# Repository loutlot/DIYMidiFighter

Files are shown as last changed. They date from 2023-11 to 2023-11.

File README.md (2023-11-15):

# DIY Midi Fighter Thing tutorial.  

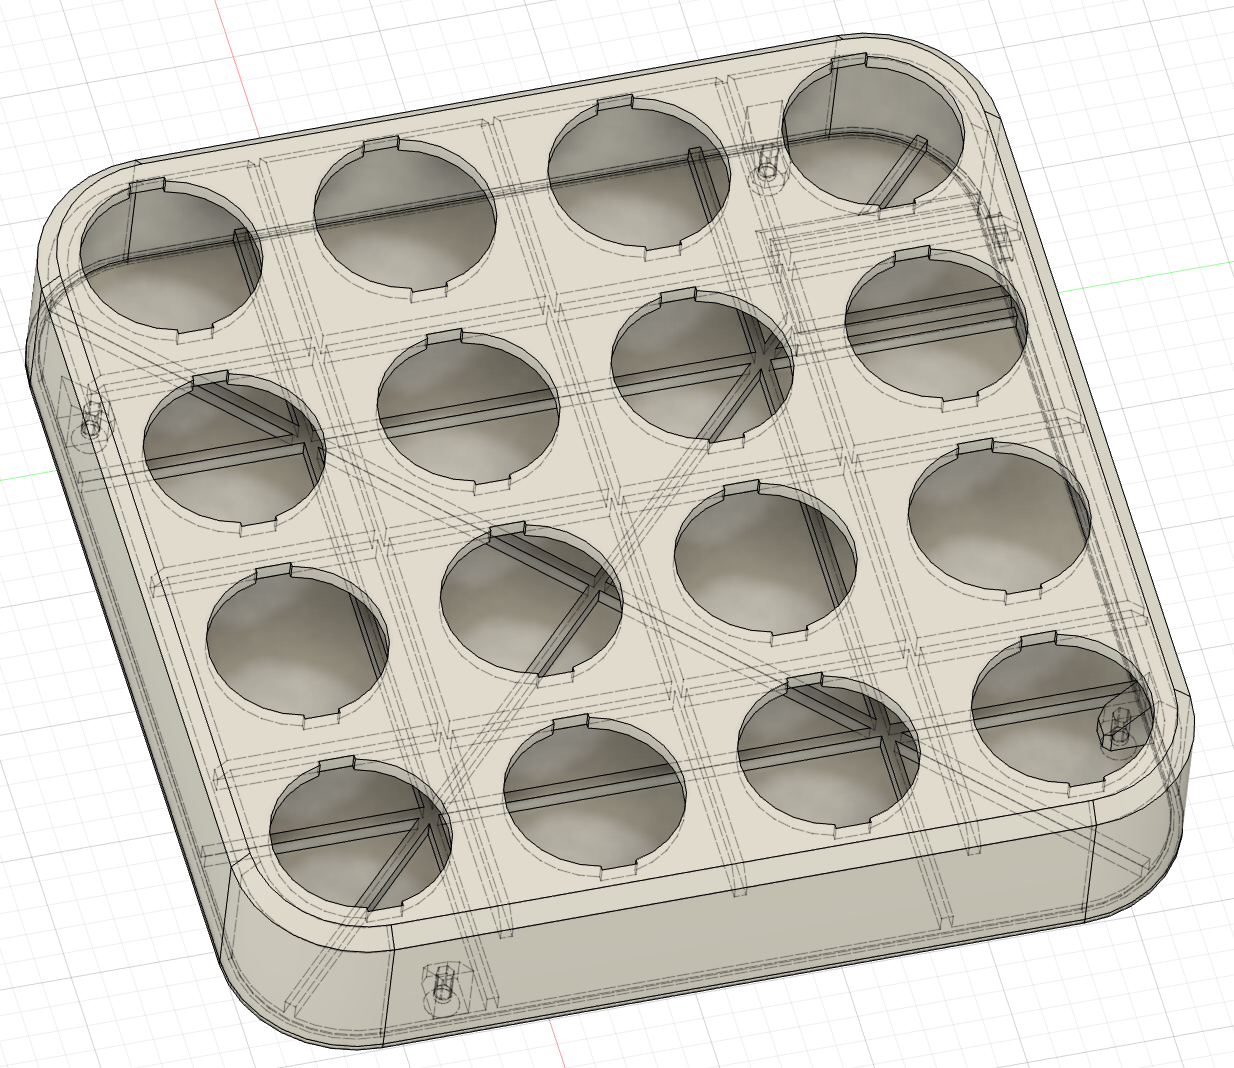
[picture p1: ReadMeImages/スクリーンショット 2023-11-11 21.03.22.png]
Main Image
  
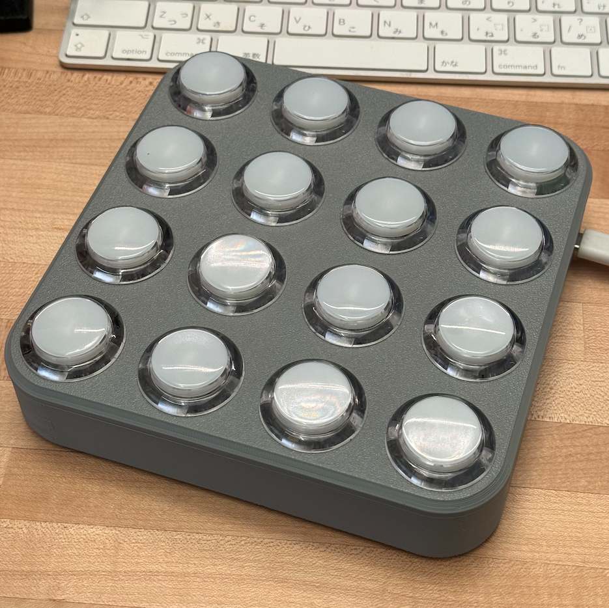
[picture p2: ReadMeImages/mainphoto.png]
Main Photo
  
This is the DIY Midi Fighter project page.  
This contains everything needed for you to go through and finish DIY Midi Fighter-ish thing build.  
  
# Item List  
  
 - **Arduino Pro Micro** * 1  
Arduino Pro Micro works with atmega 32u4 chip and compatible with Arduino Leonardo, this chip is often used for custom keyboard project since it has capability to directly send key input to PC devices.  
You can purchase chinese clone on Aliexpress  
[LINK](https://aliexpress.com/item/1005001622051348.html)  
 (I purchased "TYPE-C USB 3-6V New" version)  
**! Make sure to purhase 5V version to work correctly with LED on buttons**  
**! USB C version doesn't contain pullup resistor in it, so it doesn't work with USB-C - USB-C cable without tricks**  
  
 - **Sanwa Compatible Buttons** * 16  
 This is clone for Sanwa 30mm arcade button.  
 [LINK](https://aliexpress.com/item/4001077002366.html)  
 **!Make sure to purchase more than 16 units of this, since quality is poor and can come with bad condition**  

 - M3 x 8mm Flat Head Screw * 4  
   This is for closing a lid, cheap to purchase at Aliexpress too with items above.

 - Some Cables for internal connetions  
   Better to have more than 3 colors
 - Rubber feet * 4
   
## 3D Printing  
Check 2 stl files at [STL File](https://github.com/loutlot/DIYMidiFighter/tree/main/stl)  
In case you don't want to slice them on your own, I uploaded .gcode file to here too. [GCODE](https://github.com/loutlot/DIYMidiFighter/tree/main/gcode)  

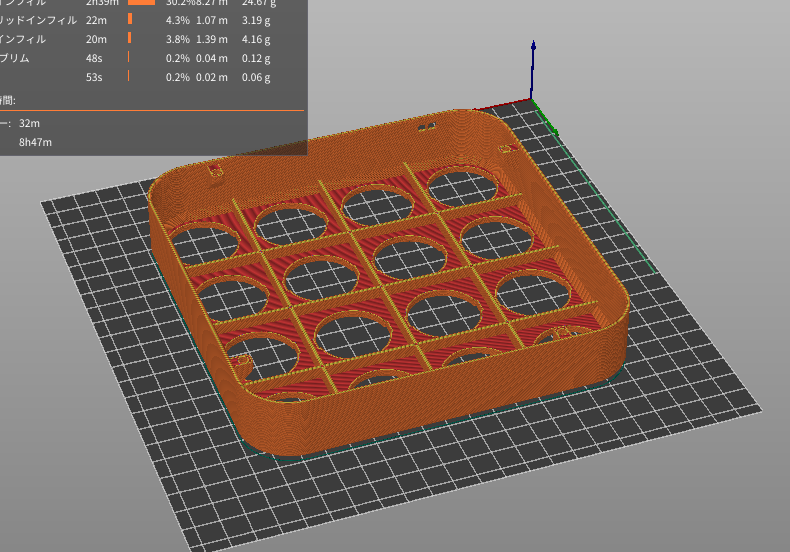
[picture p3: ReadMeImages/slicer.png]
Slicer
    
Files are designed to be printed without support material, **no need to add supports**, just putting flat face down and go print works.  
I printed with conditions below:  
 - PLA
 - 0.4mm Nozzle
 - 0.2mm Layer height  
  
It took 8 hours for main body, 6 hours for lid using my printer  
  
## Arduino coding/writing
Download [Arduino IDE](https://www.arduino.cc/en/software) first.  
Also You need to install [Control-Surface](https://github.com/tttapa/Control-Surface) library for my code to work, follow [Their Instruction](https://tttapa.github.io/Control-Surface-doc/Doxygen/d8/da8/md_pages_Installation.html) to install the library.  

DL my code [here](https://github.com/loutlot/DIYMidiFighter/blob/main/Arduino_Code/midif.ino).  
You can burn into Arduino via USB cable using Arduino IDE.  
Select "Arduino Leonardo" for device and choose USB device pops up when you plugged in.  
  
## Assembly
Assembly requires patience and little bit of soldering skills.  
Here is a basic diagram.  

### switch assembly
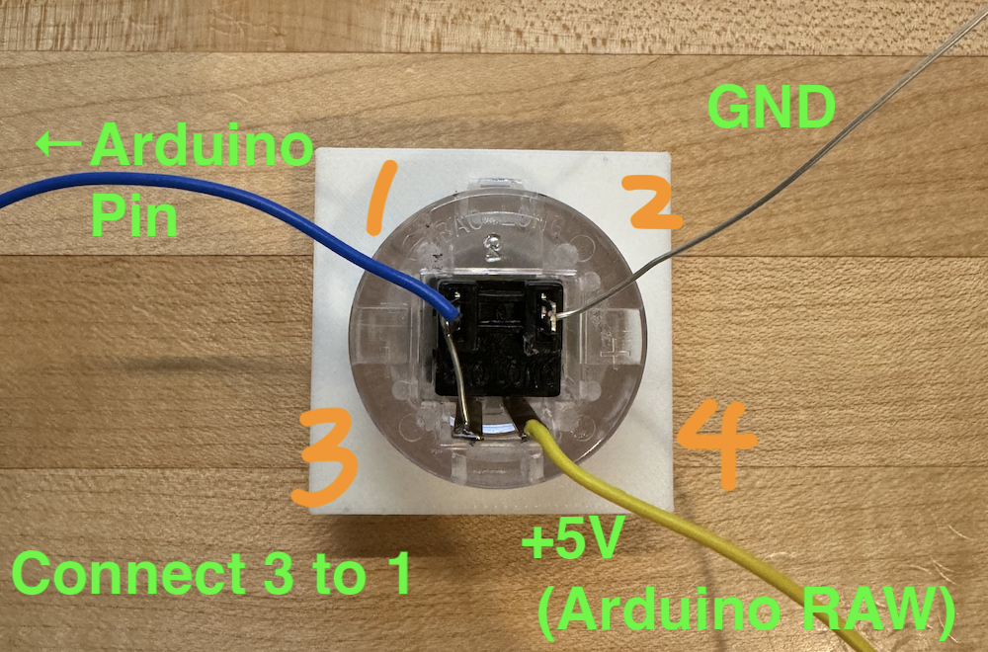
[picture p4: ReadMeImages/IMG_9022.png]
image switch
  
|PIN on Button|Function |Goes to|
|---|---|-|
|1 |Switch +|Arduino PIN & PIN 3
|2 |Switch -|Arduino GND
|3 |LED -|PIN 1
|4 |LED +|+5V (Arduino RAW)
  
Arduino reads Pin 1 on switch pulldown.  
 - Connect Pin 1 and 3 on the switch.  
 - GND and 5V+ each share connections with other switches  
  
### Connection to Arduino 
Connect wires coming from Pin1 on switches to Arduino input pins  
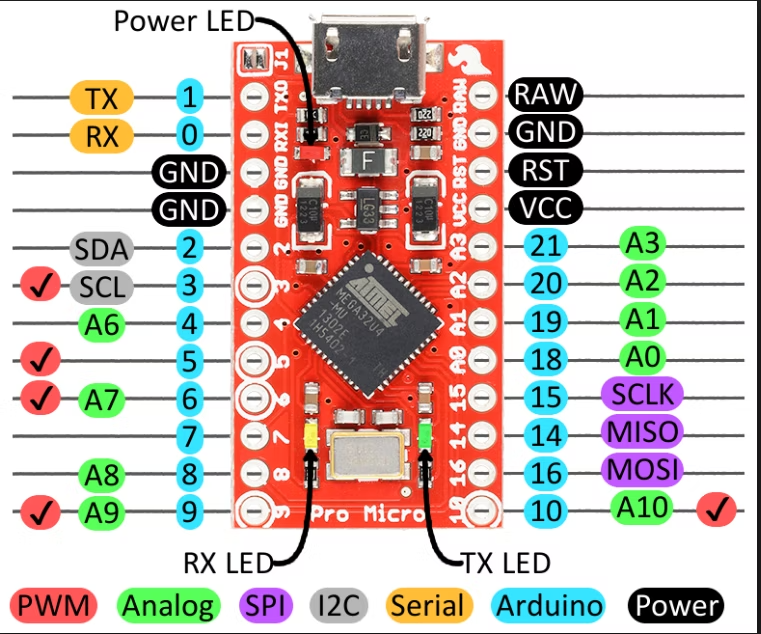
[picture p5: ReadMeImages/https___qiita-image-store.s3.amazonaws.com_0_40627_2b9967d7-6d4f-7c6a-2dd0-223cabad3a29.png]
Arduino Pinassign
  
  
Look at the blue numbering on the diagram above.  
I assigned:  
 - Pin1 to Pin9 correspond with Note C1 to A1 by order **(not pin number order, pin location order)**.  
 - Pin 10 to Pin 19 correspond with Note A#1 to D#2 by order **(not pin number order, pin location order)**.  
  
on the cord, Since C1 is the starting offset for Ableton Live drum rack.  
You can customize by editing the cord.  
Use Note Numbers Figure below for reference:  
Note Numbers
  
When you finish assembly, it should look like this.  
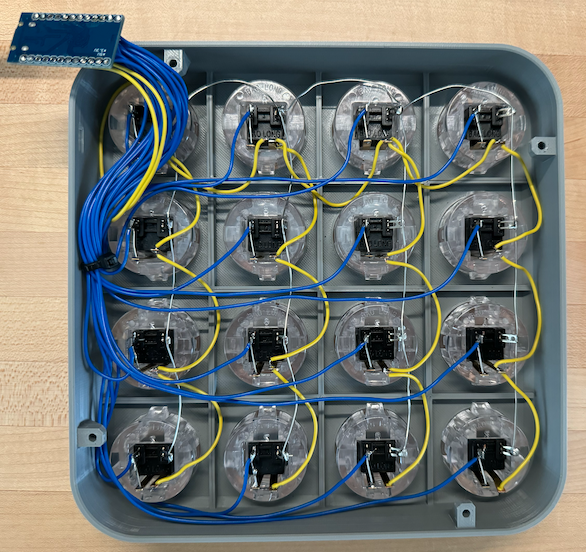
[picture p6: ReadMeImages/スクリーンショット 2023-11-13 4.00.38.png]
image finished
  
  
## Rename Device Name (Optional)
You can change device name from "Arduino Leonardo".  
Here is a [instruction](https://liveelectronics.musinou.net/MIDIdeviceName.php)

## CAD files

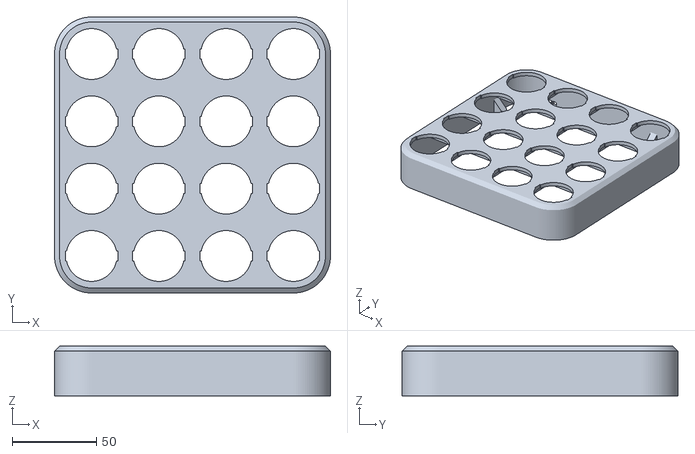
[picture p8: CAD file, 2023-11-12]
stl/midif_main.stl
164.0 x 164.0 x 29.5

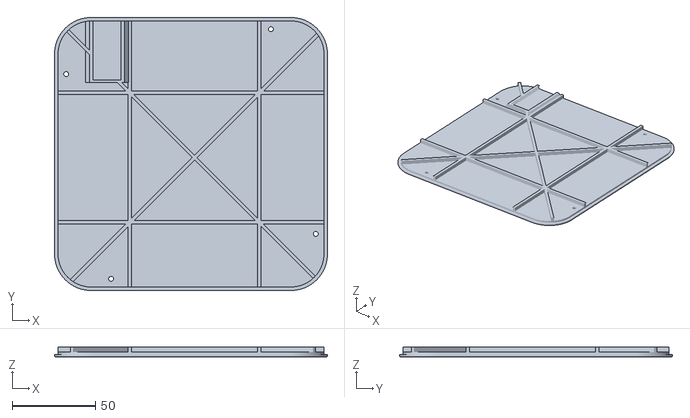
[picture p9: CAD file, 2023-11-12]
stl/midiF_lid.stl
164.0 x 164.0 x 6.00

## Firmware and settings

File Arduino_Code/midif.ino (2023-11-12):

#include <Control_Surface.h> // Include the Control Surface library
 
// Instantiate a MIDI over USB interface.
USBMIDI_Interface midi;
 
// Instantiate a NoteButton object
NoteButton buttons[] {
  {1, {36, Channel_1}},
  {0, {37, Channel_1}},
  {2, {38, Channel_1}},
  {3, {39, Channel_1}},
  {4, {40, Channel_1}},
  {5, {41, Channel_1}},
  {6, {42, Channel_1}},
  {7, {43, Channel_1}},
  {8, {44, Channel_1}},
  {9, {45, Channel_1}},
  {10, {46, Channel_1}},
  {16, {47, Channel_1}},
  {14, {48, Channel_1}},
  {15, {49, Channel_1}},
  {18, {50, Channel_1}},
  {19, {51, Channel_1}},
};

 
void setup() {
  Control_Surface.begin(); // Initialize Control Surface
}
 
void loop() {
  Control_Surface.loop(); // Update the Control Surface
}
